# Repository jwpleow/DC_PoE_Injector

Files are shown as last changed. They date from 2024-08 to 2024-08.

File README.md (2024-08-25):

# 802.3at PoE Injector, Mode B, with 12-32Vdc Input

It's too hard to find a midspan injector that takes in DC voltage.. (e.g. Phihong POE30D-1ATP-R / POE20D-1AF-R is a little hard to get a hold of)   

Disclaimer: Amateur hobbyist-grade work. I've got it printed and assembled by JLCPCB and used it successfully.

## JLCPCB Manufacturing Notes
Designed for the 4 Layer `JLC04161H-7628` - For 100Ohm impedance - 0.127mm trace spacing, 0.1402mm trace width

## Core Components

### Ethernet
| Part Name | Description | Datasheet | JLCPCB |
| - | - | - | - |
| TPS23861 | 802.3at Quad Port Power-over-Ethernet PSE Controller | [Datasheet](https://www.ti.com/lit/ds/symlink/tps23861.pdf)  | [JLCPCB](https://jlcpcb.com/partdetail/TexasInstruments-TPS23861PWR/C93245) | 
| SM51625EL | LAN 10/100/1000 Base-T (PoE++) Transformer | [Datasheet](https://wmsc.lcsc.com/wmsc/upload/file/pdf/v2/lcsc/2306061201_BOURNS-SM51625EL_C5357757.pdf) | [JLCPCB](https://jlcpcb.com/partdetail/Bourns-SM51625EL/C5357757) |
| R-RJ45R08P-C000 | RJ45, Horizontal, Shielded with LED | [Datasheet](https://wmsc.lcsc.com/wmsc/upload/file/pdf/v2/lcsc/1912111437_Ckmtw-Shenzhen-Cankemeng-R-RJ45R08P-C000_C386757.pdf) | [JLCPCB](https://jlcpcb.com/partdetail/360864-R_RJ45R08PC000/C386757) |

### Power
| Part Name | Description | Datasheet | JLCPCB |
| - | - | - | - |
| TPS7B8233QDGNRQ1 | 2.5-40V input, 3.3V 300mA output LDO | [Datasheet](https://www.ti.com/lit/ds/symlink/tps7b82-q1.pdf)  | [JLCPCB](https://jlcpcb.com/partdetail/TexasInstruments-TLV709A33DBVR/C21574006 ) | 
| LM5155QDSSRQ1 | Boost Converter | [Datasheet](https://www.ti.com/lit/ds/symlink/lm5155-q1.pdf) | [JLCPCB](https://jlcpcb.com/partdetail/TexasInstruments-LM5155QDSSRQ1/C1849528) |

## References
- [TPS23861 Datasheet](https://www.ti.com/lit/ds/symlink/tps23861.pdf)
- [TPS23861 Evaluation Module](https://www.ti.com/lit/ug/sluuay8e/sluuay8e.pdf)
- [TPS23861 Power-On Considerations](https://www.ti.com/lit/an/slva723/slva723.pdf)
- [MAX5945EV Kit](https://www.analog.com/media/en/technical-documentation/data-sheets/MAX5945EVKIT-MAX5945EVSYS.pdf)

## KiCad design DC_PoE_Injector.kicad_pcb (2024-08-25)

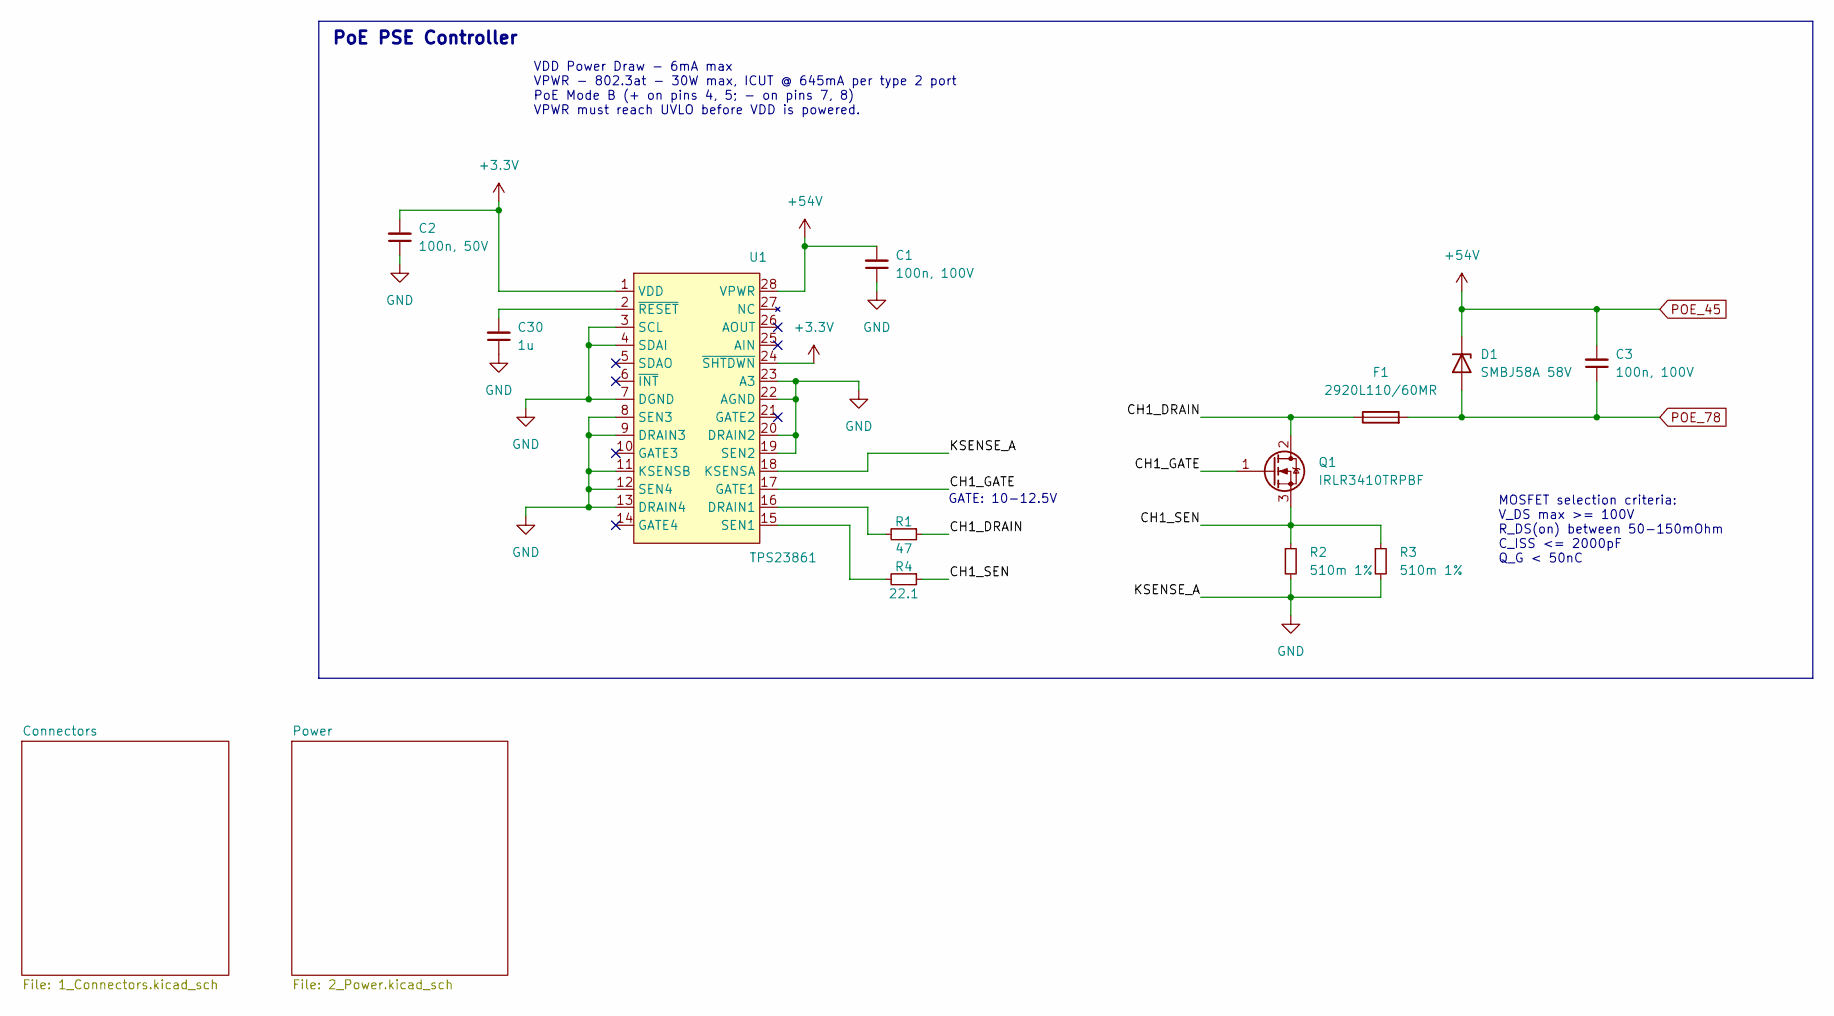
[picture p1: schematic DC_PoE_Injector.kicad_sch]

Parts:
C1, C3: 100n, 100V; C_0805_2012Metric; LCSC C28233
C2: 100n, 50V; C_0603_1608Metric; LCSC C14663
C30: 1u; C_0805_2012Metric; LCSC C28323
D1: SMBJ58A 58V; D_SMB; LCSC C135085
F1: 2920L110/60MR; Fuse_2920_7451Metric; LCSC C315903
Q1: IRLR3410TRPBF; TO-252-2-JLCPCB; LCSC C3017
R1: 47; R_0603_1608Metric; LCSC C23182
R2, R3: 510m 1%; R_0805_2012Metric; LCSC C491234
R4: 22.1; R_0603_1608Metric; LCSC C22958
U1: TPS23861; LCSC C93245

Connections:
+3.3V: C2.2, U1.1 (VDD), U1.24 (~SHTDWN); also elsewhere on the board
/CH1_DRAIN: F1.1, Q1.2 (D), R1.1
/CH1_GATE: Q1.1 (G), U1.17 (GATE1)
/CH1_SEN: Q1.3 (S), R2.1, R3.1, R4.1
GND: C1.1, C2.1, C30.1, R2.2, R3.2, U1.3 (SCL), U1.4 (SDAI), U1.7 (DGND), U1.8 (SEN3), U1.9 (DRAIN3), U1.11 (KSENSB), U1.12 (SEN4), U1.13 (DRAIN4), U1.18 (KSENSA), U1.19 (SEN2), U1.20 (DRAIN2), U1.22 (AGND), U1.23 (A3); also elsewhere on the board
unnamed: R1.2, U1.16 (DRAIN1)
unnamed: R4.2, U1.15 (SEN1)
unnamed: C30.2, U1.2 (~RESET)
POE_45: C1.2, C3.2, D1.1 (K), U1.28 (VPWR); also elsewhere on the board
POE_78: C3.1, D1.2 (A), F1.2; also elsewhere on the board

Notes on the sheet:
PoE PSE Controller
GATE: 10-12.5V
MOSFET selection criteria: V_DS max >= 100V R_DS(on) between 50-150mOhm C_ISS <= 2000pF Q_G < 50nC
VDD Power Draw - 6mA max VPWR - 802.3at - 30W max, ICUT @ 645mA per type 2 port PoE Mode B (+ on pins 4, 5; - on pins 7, 8) VPWR must reach UVLO before VDD is powered.

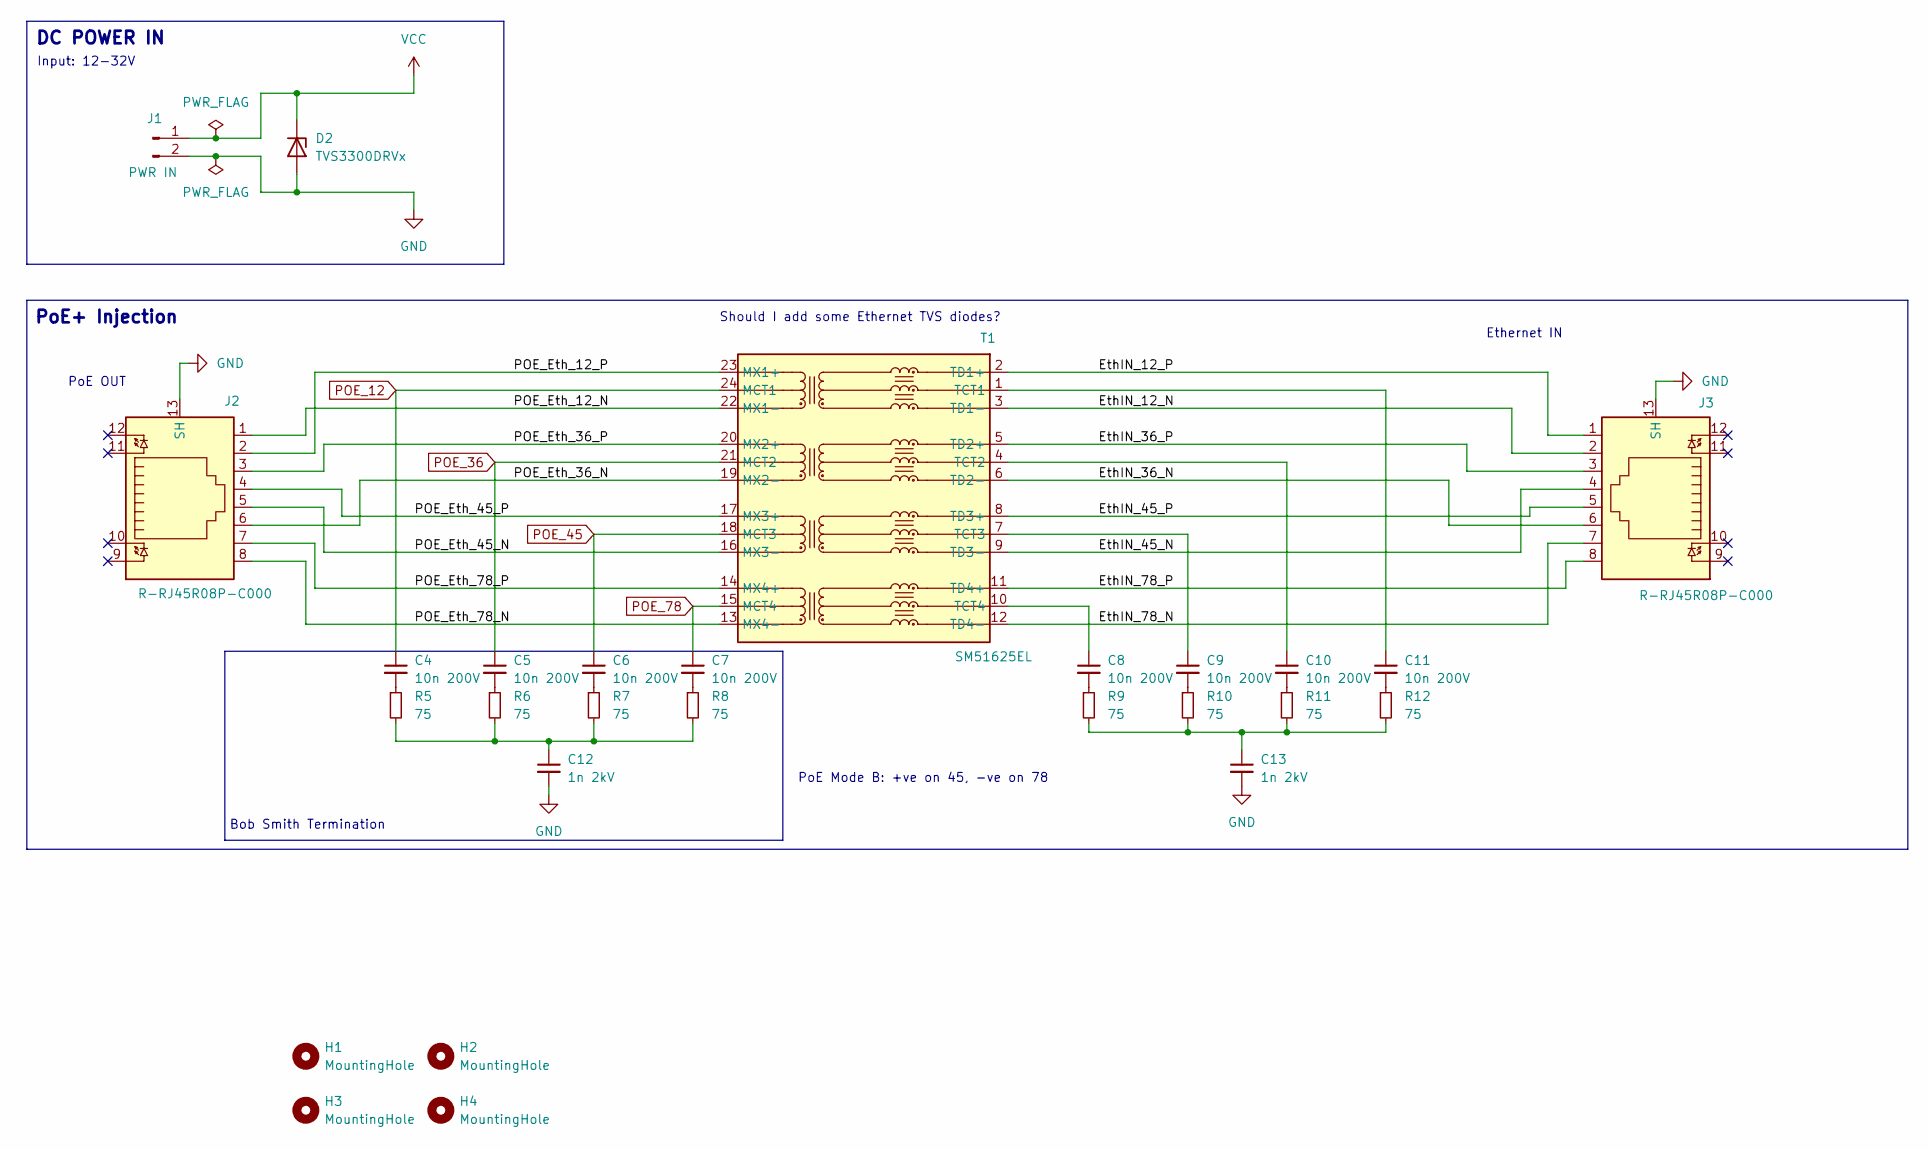
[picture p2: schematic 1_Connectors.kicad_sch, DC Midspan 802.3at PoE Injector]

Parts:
C4, C5, C6, C7, C8, C9, C10, C11: 10n 200V; C_0805_2012Metric; LCSC C106844
C12, C13: 1n 2kV; C_1206_3216Metric; LCSC C9196
D2: TVS3300DRVx; DRV0006A; LCSC C2863624
H1, H2, H3, H4: MountingHole; MountingHole_3.2mm_M3
J1: PWR IN; PhoenixContact_SPT_2.5_2-H-5.0_1x02_P5.0mm_Horizontal; LCSC C5443538
J2, J3: R-RJ45R08P-C000; LCSC C386757
R5, R6, R7, R8, R9, R10, R11, R12: 75; R_0805_2012Metric; LCSC C20638
T1: SM51625EL; Manufacturer_Part_Number SM51625EL; Mouser Part Number 652-SM51625EL

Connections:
/Connectors/EthIN_12_N: J3.2, T1.3 (TD1-)
/Connectors/EthIN_12_P: J3.1, T1.2 (TD1+)
/Connectors/EthIN_36_N: J3.6, T1.6 (TD2-)
/Connectors/EthIN_36_P: J3.3, T1.5 (TD2+)
/Connectors/EthIN_45_N: J3.4, T1.9 (TD3-)
/Connectors/EthIN_45_P: J3.5, T1.8 (TD3+)
/Connectors/EthIN_78_N: J3.7, T1.12 (TD4-)
/Connectors/EthIN_78_P: J3.8, T1.11 (TD4+)
/Connectors/POE_Eth_12_N: J2.1, T1.22 (MX1-)
/Connectors/POE_Eth_12_P: J2.2, T1.23 (MX1+)
/Connectors/POE_Eth_36_N: J2.6, T1.19 (MX2-)
/Connectors/POE_Eth_36_P: J2.3, T1.20 (MX2+)
/Connectors/POE_Eth_45_N: J2.5, T1.16 (MX3-)
/Connectors/POE_Eth_45_P: J2.4, T1.17 (MX3+)
/Connectors/POE_Eth_78_N: J2.8, T1.13 (MX4-)
/Connectors/POE_Eth_78_P: J2.7, T1.14 (MX4+)
GND: C12.2, C13.2, D2.1 (A), D2.2 (A), D2.3 (A), D2.7 (A), J1.2, J2.13 (SH), J3.13 (SH); also elsewhere on the board
unnamed: C4.2, R5.1
unnamed: C5.2, R6.1
unnamed: C6.2, R7.1
unnamed: C7.2, R8.1
unnamed: C8.2, R9.1
unnamed: C9.2, R10.1
unnamed: C10.2, R11.1
unnamed: C11.2, R12.1
unnamed: C12.1, R5.2, R6.2, R7.2, R8.2
unnamed: C13.1, R9.2, R10.2, R11.2, R12.2
unnamed: C11.1, T1.1 (TCT1)
unnamed: C10.1, T1.4 (TCT2)
unnamed: C9.1, T1.7 (TCT3)
unnamed: C8.1, T1.10 (TCT4)
POE_12: C4.1, T1.24 (MCT1)
POE_36: C5.1, T1.21 (MCT2)
POE_45: C6.1, T1.18 (MCT3); also elsewhere on the board
POE_78: C7.1, T1.15 (MCT4); also elsewhere on the board
VCC: D2.4 (K), D2.5 (K), D2.6 (K), J1.1; also elsewhere on the board

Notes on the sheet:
Input: 12-32V
PoE Mode B: +ve on 45, -ve on 78
PoE OUT
Ethernet IN
Should I add some Ethernet TVS diodes?
Bob Smith Termination
DC POWER IN
PoE+ Injection

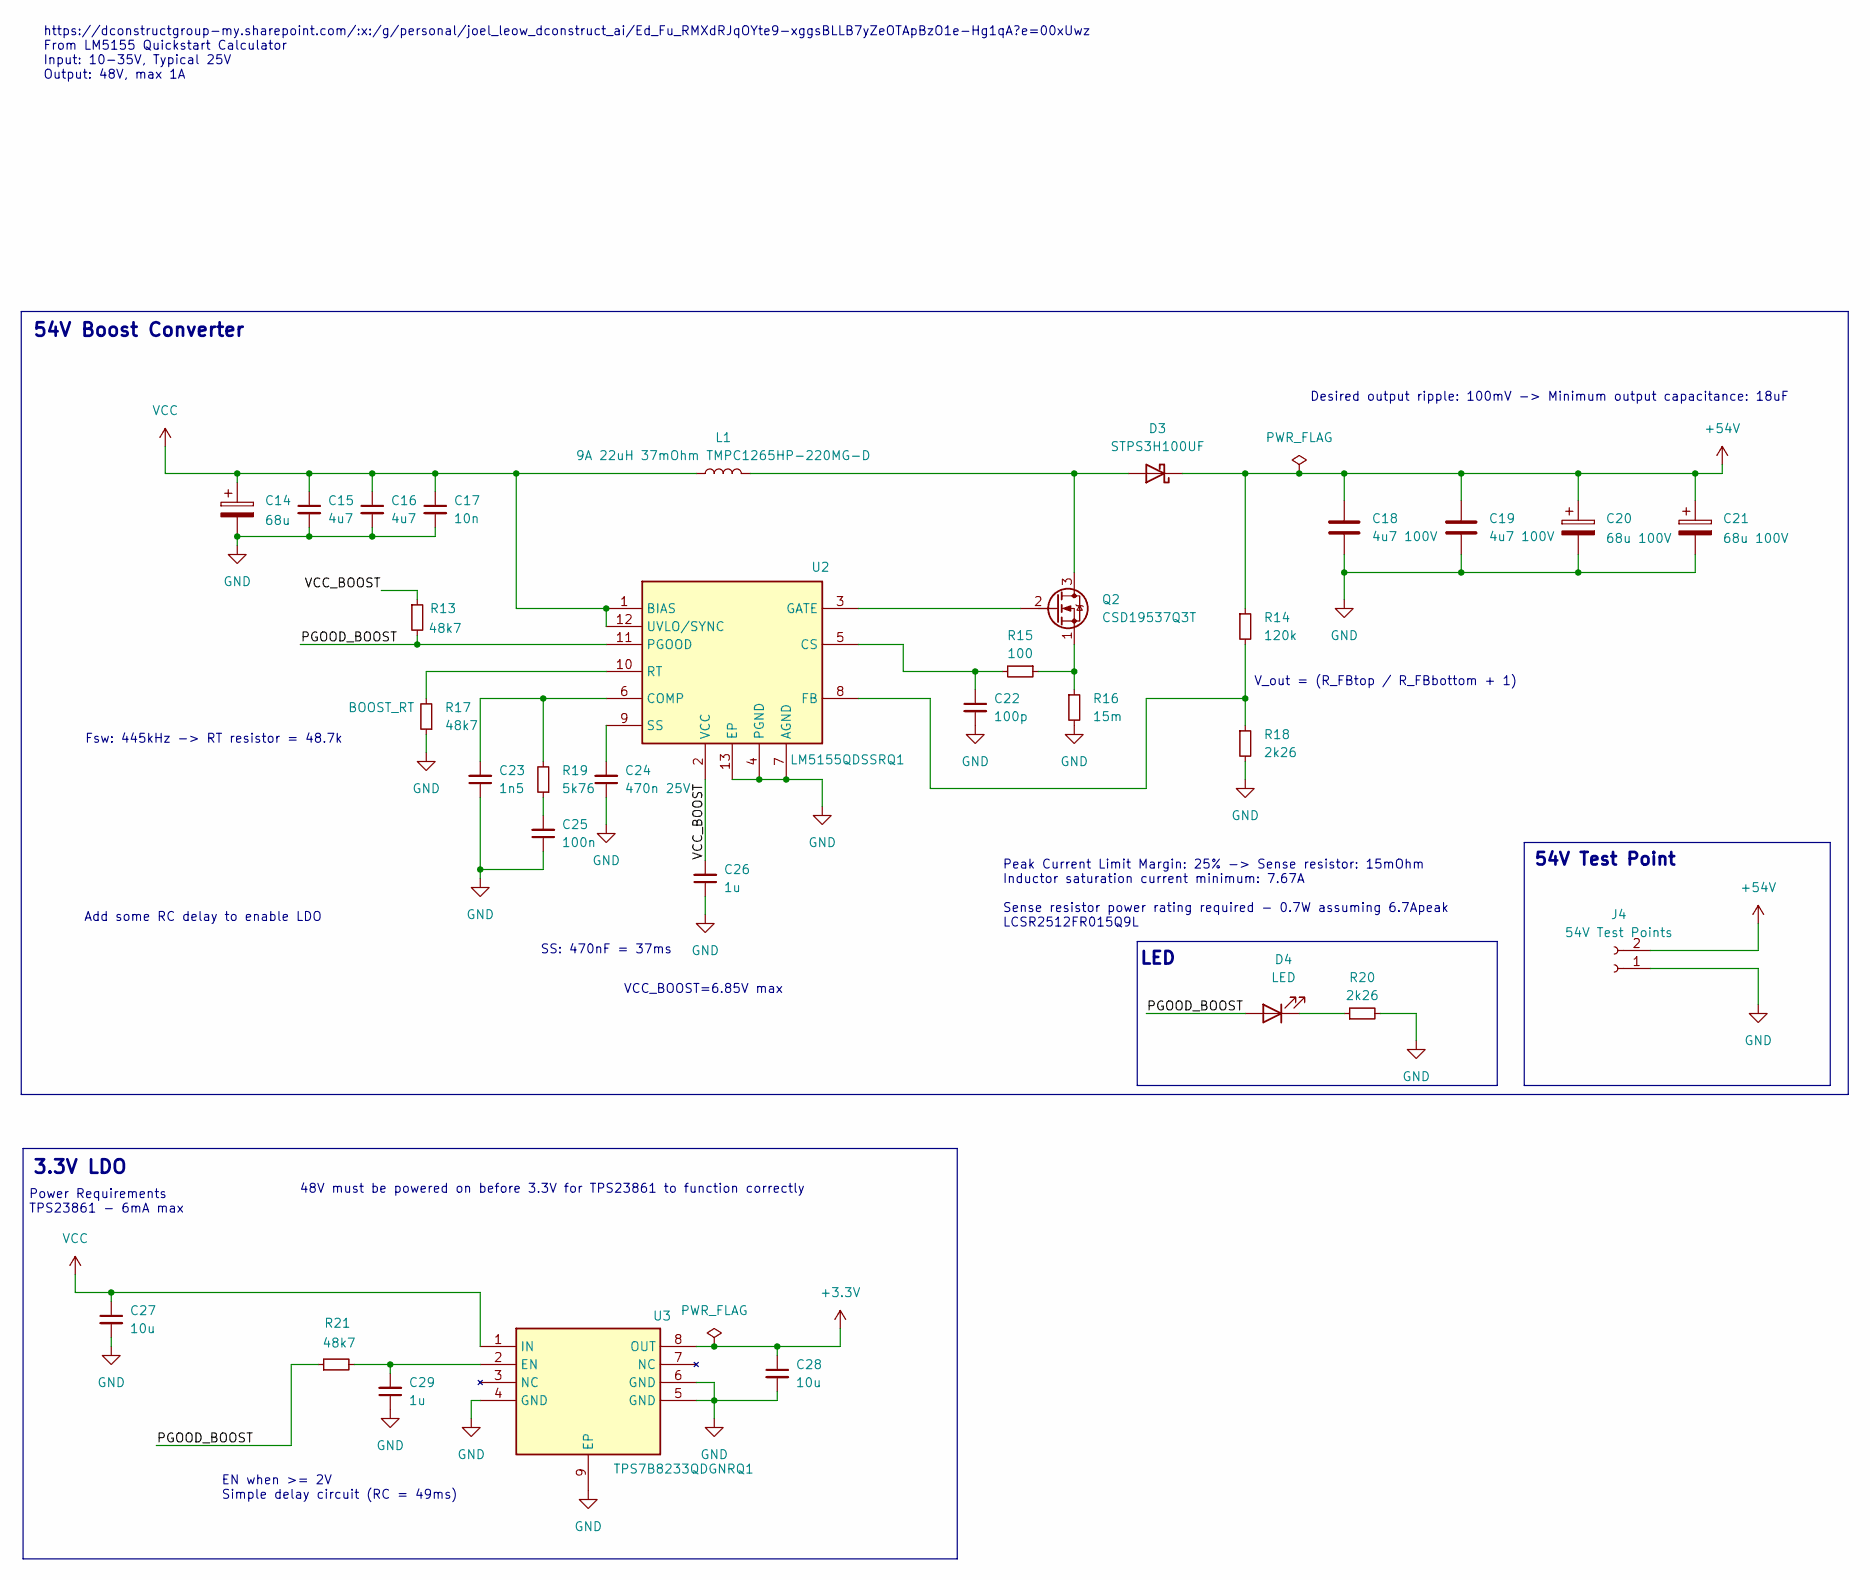
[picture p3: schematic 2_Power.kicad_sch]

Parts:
C14: 68u; CP_Elec_12.5x13.5; LCSC C278544
C15, C16: 4u7; C_1206_3216Metric; LCSC C29823
C17: 10n; C_0603_1608Metric; LCSC C57112
C18, C19: 4u7 100V; C_1210_3225Metric; LCSC C381466
C20, C21: 68u 100V; CP_Elec_12.5x13.5; LCSC C278544
C22: 100p; C_0402_1005Metric; LCSC C1546
C23: 1n5; R_0603_1608Metric; LCSC C1595
C24: 470n 25V; C_0603_1608Metric; LCSC C1623
C25: 100n; R_0603_1608Metric; LCSC C14663
C26, C29: 1u; C_0805_2012Metric; LCSC C28323
C27, C28: 10u; C_0805_2012Metric; LCSC C440198
D3: STPS3H100UF; D_SMBflat; LCSC C155643
D4: LED; LED_0603_1608Metric; LCSC C2286
J4: 54V Test Points; SolderWire-2.5sqmm_1x02_P8.8mm_D2.4mm_OD4.4mm
L1: 9A 22uH 37mOhm TMPC1265HP-220MG-D; L_TaiTech_TMPC1265_13.5x12.5mm; LCSC C305224
Q2: CSD19537Q3T
R13, R17, R21: 48k7; R_0402_1005Metric; LCSC C26981
R14: 120k; R_0603_1608Metric; LCSC C25808
R15: 100; R_0603_1608Metric; LCSC C22775
R16: 15m; R_2512_6332Metric; LCSC C520400
R18, R20: 2k26; R_0603_1608Metric; LCSC C22904
R19: 5k76; R_0603_1608Metric; LCSC C23070
U2: LM5155QDSSRQ1; DSS0012x; Manufacturer_Part_Number LM5155QDSSRQ1; Mouser Part Number 595-LM5155QDSSRQ1
U3: TPS7B8233QDGNRQ1; DGN0008G; Manufacturer_Part_Number TPS7B8233QDGNRQ1; Mouser Part Number 595-TPS7B8233QDGNRQ1

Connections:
+3.3V: C28.1, U3.8 (OUT); also elsewhere on the board
/Power/PGOOD_BOOST: D4.2 (A), R13.2, R21.1, U2.11 (PGOOD)
/Power/VCC_BOOST: C26.2, R13.1, U2.2 (VCC)
GND: C14.2, C15.2, C16.2, C17.2, C18.2, C19.2, C20.2, C21.2, C22.2, C23.1, C24.1, C25.1, C26.1, C27.2, C28.2, C29.1, J4.1, R16.2, R17.1, R18.2, R20.2, U2.4 (PGND), U2.7 (AGND), U2.13 (EP), U3.4 (GND), U3.5 (GND), U3.6 (GND), U3.9 (EP); also elsewhere on the board
unnamed: C25.2, R19.1
unnamed: D3.2 (A), L1.2, Q2.3 (D)
unnamed: D4.1 (K), R20.1
unnamed: Q2.2 (G), U2.3 (GATE)
unnamed: Q2.1 (S), R15.1, R16.1
unnamed: C23.2, R19.2, U2.6 (COMP)
unnamed: C22.1, R15.2, U2.5 (CS)
unnamed: R14.2, R18.1, U2.8 (FB)
unnamed: R17.2, U2.10 (RT)
unnamed: C24.2, U2.9 (SS)
unnamed: C29.2, R21.2, U3.2 (EN)
POE_45: C18.1, C19.1, C20.1, C21.1, D3.1 (K), J4.2, R14.1; also elsewhere on the board
VCC: C14.1, C15.1, C16.1, C17.1, C27.1, L1.1, U2.1 (BIAS), U2.12 (UVLO/SYNC), U3.1 (IN); also elsewhere on the board

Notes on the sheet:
SS: 470nF = 37ms
Desired output ripple: 100mV -> Minimum output capacitance: 18uF
V_out = (R_FBtop / R_FBbottom + 1)
LED
Power Requirements TPS23861 - 6mA max
54V Test Point
Fsw: 445kHz -> RT resistor = 48.7k
Add some RC delay to enable LDO
3.3V LDO
Peak Current Limit Margin: 25% -> Sense resistor: 15mOhm Inductor saturation current minimum: 7.67A Sense resistor power rating required - 0.7W assuming 6.7Apeak LCSR2512FR015Q9L
48V must be powered on before 3.3V for TPS23861 to function correctly
EN when >= 2V Simple delay circuit (RC = 49ms)
54V Boost Converter
https://dconstructgroup-my.sharepoint.com/:x:/g/personal/joel_leow_dconstruct_ai/Ed_Fu_RMXdRJqOYte9-xggsBLLB7yZeOTApBzO1e-Hg1qA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 From LM5155 Quickstart Calculator Input: 10-35V, Typical 25V Output: 48V, max 1A
VCC_BOOST=6.85V max

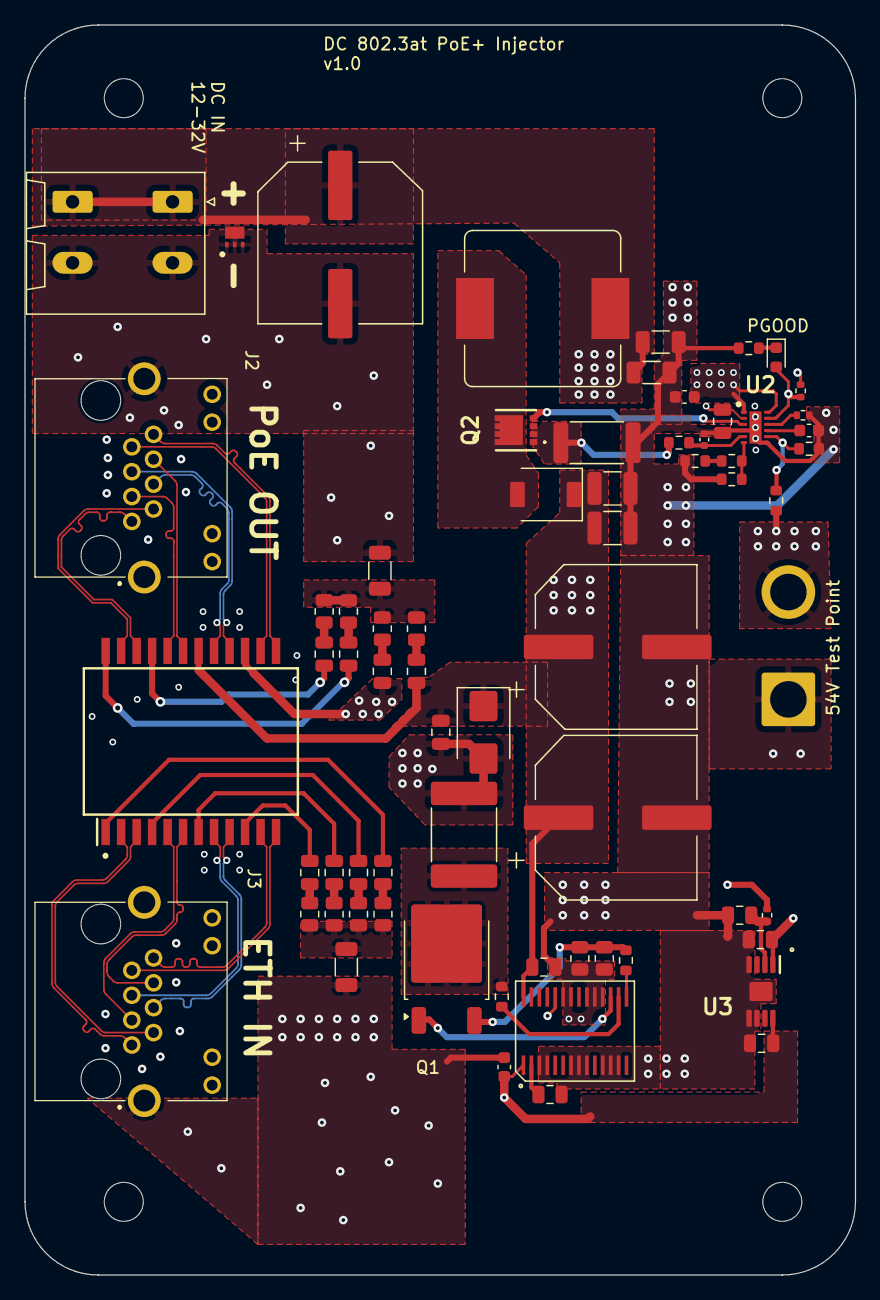
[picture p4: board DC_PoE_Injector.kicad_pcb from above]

Board: 4 copper layers, 68.1 x 102.5 mm, 71 parts (0 on the bottom side), 56 nets.

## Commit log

2024-07-21 Add initial repo setup
    [DC_PoE_Injector.kicad_pcb, DC_PoE_Injector.kicad_sch]
2024-07-27 add readme
    [DC_PoE_Injector.kicad_sch]
2024-07-27 Adding some skeleton
    [1_Connectors.kicad_sch, 2_Power.kicad_sch, DC_PoE_Injector.kicad_pcb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]
2024-07-28 Add magnetics for poe
    [1_Connectors.kicad_sch, DC_PoE_Injector.kicad_sch]
2024-08-04 Add boost converter
    [1_Connectors.kicad_sch, 2_Power.kicad_sch, DC_PoE_Injector.kicad_sch]
2024-08-09 finish layout
    [1_Connectors.kicad_sch, 2_Power.kicad_sch, DC_PoE_Injector.kicad_pcb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]
2024-08-13 Some cleanups
    [2_Power.kicad_sch, DC_PoE_Injector.kicad_pcb, DC_PoE_Injector.kicad_sch]
2024-08-25 add silkscreen labels for power
    [1_Connectors.kicad_sch, 2_Power.kicad_sch, DC_PoE_Injector.kicad_pcb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]
2024-08-25 update kicadlib
2024-08-25 fix some outdated footprints
    [DC_PoE_Injector.kicad_pcb]
